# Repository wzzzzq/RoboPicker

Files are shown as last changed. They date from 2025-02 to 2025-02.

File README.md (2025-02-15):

# RoboPicker

## 项目简介

RoboPicker是一个由王子谦于2022年在华师大二附中科创班就读期间开发的机器人项目，该项目获得了上海市第37届科创大赛一等奖。RoboPicker由三个主要部分组成：底盘、机械臂和openmv相机。

## 主要研究内容 & 成果

- 麦克纳姆轮底盘的全向解耦与PID控制
- 天地飞sbus接收机的信号解码并应用于手动控制机器人
- 简单的小车自动运行程序
- 通过python为openmv编写颜色识别程序追踪果蔬
- 初步研究了使用神经网络追踪番茄
- 六轴机械臂的姿态解算与控制
- 使用PID算法控制机械臂追踪番茄
- 机械臂arduino主控，底盘arduino主控与openmv模块的uart通讯

## 仓库内容

- **代码**：在`./code`中，包含了RoboPicker的所有代码，代码分为底盘、机械臂和相机三个部分。
- **CAD文件**：在`./CADs`中，包含了RoboPicker的所有CAD设计文件。
- **arduino拓展板设计图**：`./PCB/mega_shield.pcbdoc`文件是RoboPicker的电路图。

## 结构图

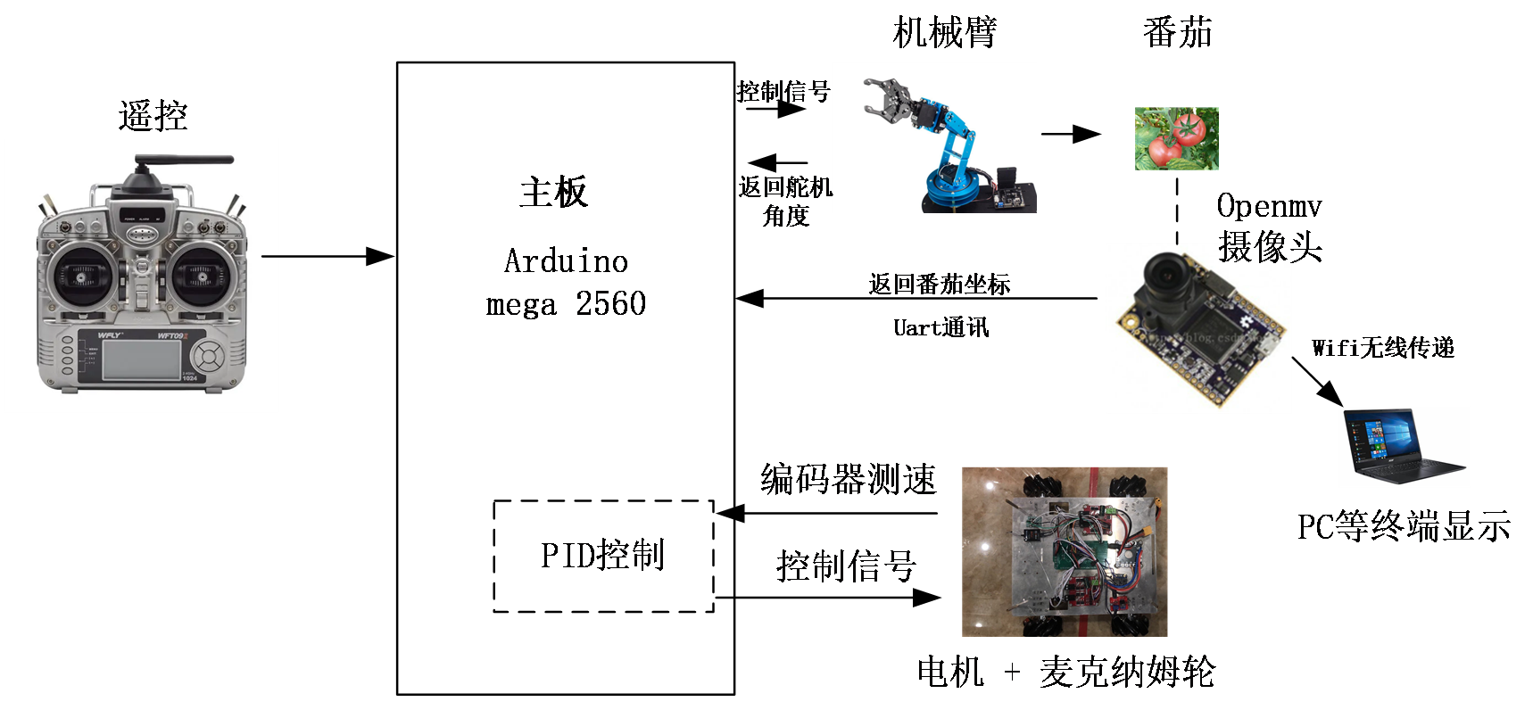
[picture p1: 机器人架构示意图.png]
机器人结构示意图


## 机器人成品展示
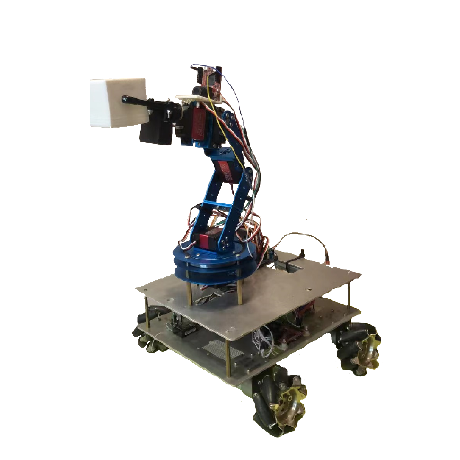
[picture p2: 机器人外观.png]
机器人外观展示


## 致谢

感谢所有为本项目提供支持和帮助的人们，特别感谢第37届科创大赛评审团对本项目的认可。

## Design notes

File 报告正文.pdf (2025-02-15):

## 第 37 届上海市青少年科技创新大赛

# 基于 Openmv 视觉识别和麦克纳姆轮

# 底盘的自动采摘番茄机器人

# 高中组 个人项目

二零二二年一月

## 基于 Openmv 视觉识别和麦克纳姆轮底盘的自动

## 采摘番茄机器人

摘 要

随着我国全面推动机器人产业发展，农业智能化进程不断提速，

从国内外农业机器人的发展来看，研制智能农业机器人，利用智能农

业机器人转变农业的生产方式，从而实现农业的可持续绿色发展是必

然的趋势。当前国内外农业机器人仍然存在智能化程度不高、采摘效

果不理想等问题。本课题秉承“智慧农业、科技创新、智能方案、机器

物联”的发展理念，分析了采摘机器人特点及国内外采摘机器人的进

展与现状，并基于此，研究基于麦克纳姆轮全向轮底盘和使用 Openmv

智能摄像头和机器视觉、人工智能技术以及六轴机械臂的智能番茄采

摘机器人。本课题实现了麦克纳姆轮底盘控制、数字 PID 闭环速度控

制、视觉识别和姿态解算算法等，并初步实现了番茄采摘机器人的智

能控制、移动行走路径规划和其他基本功能，并初步验证了自动驾驶

算法。它具有控制灵敏，动作灵活，便于操作的优点。

关键词： 机器人 麦克纳姆轮 Openmv 智能摄像头 番茄采摘 智

能控制

目录

1.1 智能农业采摘机器人研究现状·······················································3 1.2 智能农业采摘机器人发展趋势·······················································4 1.3 本文主要研究内容 ······································································4

2.1 底盘设计 ··················································································6 2.1.1 底盘设计 ··········································································6 2.1.2 电机转速读取与 PID 控制···················································10 2.1.3 遥控信号读取 ··································································11 2.1.4 电机控制 ········································································11 2.2 自动驾驶算法 ··········································································12 2.3 机械臂 ···················································································12 2.3.1 硬件设计 ········································································12 2.3.2 姿态解算 ········································································14 2.3.3 舵机控制 ········································································16 2.4 视觉识别 ················································································17 2.5 WIFI 无线通讯··········································································19

3.1 底盘运动能力测试 ····································································20 3.2 遥控信号接受测试 ····································································21 3.2.1 取反电路测试 ··································································21 3.2.2 串口通信代码测试 ····························································22 3.3 六轴机械臂测试 ·······································································23 3.3.1 姿态解算算法测试 ····························································23 3.3.2 机械臂摘取测试 ·······························································23 3.4 Openmv 摄像头测试···································································24 3.5 WIFI 模块测试··········································································25 3.6 TOF 光学测距传感器测试 ···························································26

4.1 结论 ······················································································27 4.2 展望 ······················································································27

## 第一章 前言

### 1.1 智能农业采摘机器人研究现状

“智慧农业”一词在近些年被频繁提起，各种自动化设备和监测系统也日渐

代替传统农业生产中落后、繁杂的工作。例如极飞科技等专注研发农业科技的

公司所推出的无人机产品，可以帮助农户完成打药、施肥、播种等工作，同时

还能实现多种智能监测设备，帮助农户观察作业的生长状况。

智能机器人在现代农业生产中的广泛应用，可以帮助农户解决许多繁重且

乏味的工作。以水果采摘机器人为例，每次一到果园收获时期，果场主就需要

聘请大量的人力去完成采摘的工作。而水果采摘机器人就能够帮助农场主节省

大量的时间和人力成本。

挪威环境与生命科学大学最近展出了一款名为 Noronn 的采摘机器人，这是

一款能够分辨种植在塑料隧道上的草莓成熟程度，并根据大小分类的自动采摘

机器人。这一款草莓机器人已经被欧洲的大型草莓种植园广泛采用。然而，这

一款机器人虽然可以实现 24 小时工作，但他并不适用于国内常见的田间栽培的

草莓。

美国 Abundant Robotics 公司，是近年来比较受关注的农业机器人初创科技

公司。凭借其研发的苹果采摘机器人，该公司在 2017 年就得到了 A 轮融资。

2019 年上半年，这个苹果机器人正式在新西兰投入商用。据悉，这款历时四年

研发的苹果采摘机器人备受关注。该款机器人借助先进的计算机视觉技术，采

取真空抽吸系统采摘苹果，可以准确绕开未成熟的苹果，而农场的工作人员只

需在远处进行操控即可。

我国华南农业大学研发团队早在数年前就研发出荔枝采摘机器人。机器人

效率为每小时采摘 40 斤荔枝，是人工采摘的两倍之多。这款机器人采用的是双

目立体视觉系统，可以对荔枝进行定位，获得视野内多个目标，然后自主规划

采摘作业路径进行，最后伸出机械臂末端的拟人夹指来剪断果枝，摘取果实。

除此之外还有其他各种 AI 水果采摘机器人的研发和推广都在进行当中，相

信未来的农业生产过程中，它们会为我们大幅降低成本并提高农业生产效率。

### 1.2 智能农业采摘机器人发展趋势

随着城市化的发展和农业劳动力的不断减少，新型农业生产模式的应用和新

技术的开发迫在眉睫，农业机器人将成为未来农业生产活动的核心。采摘机器人

作为农业机器人的一个重要分支，具有极大的发展潜力。

随着农业生产模式和新技术的发展和应用，农业机器人将成为农业生产的主

力军，采摘机器人作为农业机器人的重要类型具有很大的发展潜力。语音识别、

图像识别、大数据分析、运动学、传感器技术、控制技术和计算信息处理等更多

最新技术在农业机器人中的应用，使得农业数字化和智能化水平不断提高。

我国人口众多，幅员辽阔，农业是我国的支柱产业，随着智慧农业水平的提

高，采摘机器人大有用武之地。

目前，蔬果采摘机器人研究中仍然存在一些问题，例如机器人的视觉识别能

力不够，在复杂背景和夜间环境下的工作能力还不够理想等。今后应当将人机协

作，开放结构和多传感器融合的方法不断应用在农业机器人的研究中，尤其是将

人工智能、深度学习等新型技术应用于蔬果采摘机器人的技术开发之中。

### 1.3 本文主要研究内容

本课题首先对几种典型采摘机器人进行研究，分析了国内外采摘机器人的进

展与现状以及发展趋势。在此基础上，本课题基于 Openmv 视觉识别和麦克纳姆

轮底盘的自动采摘番茄机器人，机器人集可移动载体、机械手臂、夹持器、移动

机构及智能控制模块于一身，采用视觉技术、避障技术等实现了水果采摘机器人

的移动行走路径规划、果实成熟度自动判断及定位识别功能。

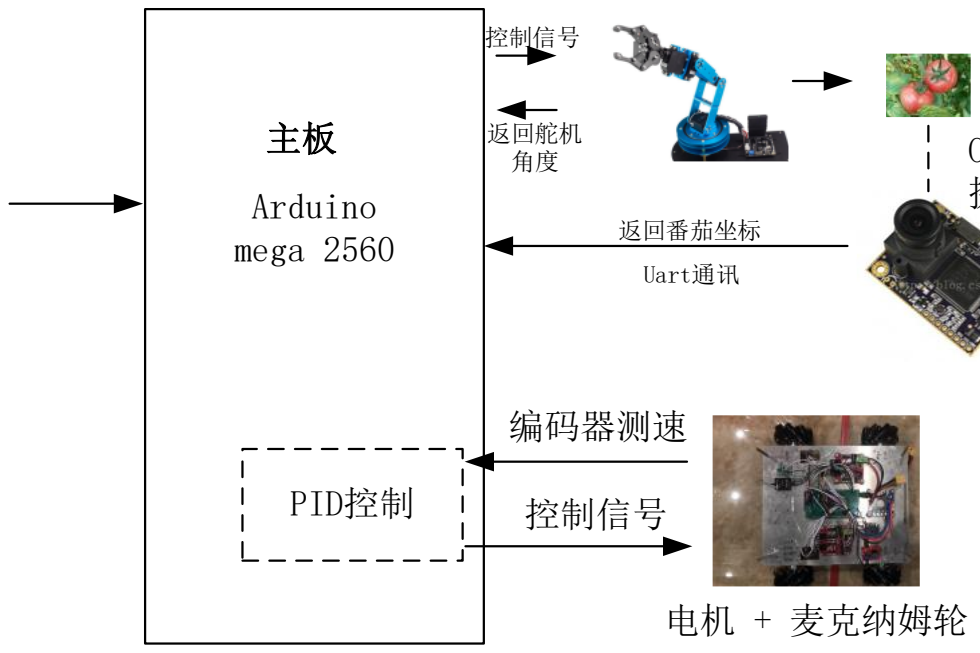
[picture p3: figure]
Arduino mega 2560; 电机 + 麦克纳姆轮; 编码器测速; PID控制; 控制信号; 返回舵机 角度; 返回番茄坐标; Uart通讯

图 1 系统结构框图

系统架构如图 1 所示，本文的组织结构如下：

第一章智能农业机器人的研究现状和发展趋势，阐述了本文的主要研究内容。

第二章阐述了本文的研究内容，包括采摘机器人的底盘设计及控制算法、机

械臂的设计和姿态解算、舵机控制，以及对于采摘机器人至关重要的视觉识别算

法及其改进。

第三章阐述了本课题农业机器人的测试过程与测试结果。

第四章总结课题，并做出了技术展望。

第五章为本课题的参考文献。

第六章则为本课题开展过程中的心得感受。

PC等终端显示

Openmv
摄像头
机械臂 | 番茄

Wifi无线传递

遥控

## 第二章 研究过程

### 2.1 底盘设计

采摘机器人集多种技术与功能于一体，其底盘作为重要部件之一，它承载

了机器人的定位导航及避障等多种功能。根据结构的不同，机器人底盘可分为

轮式、多足式及履带式等。本课题采用轮式机器人底盘，它的底盘平稳性更

好、运动噪音更低，且便于装拆及维护。本节将介绍底盘设计的具体过程，包

括底盘结构设计、电机转速读取与 PID 控制、遥控模块及电机控制。

### 2.1.1 底盘设计

轮式结构采摘机器人以驱动麦克纳姆轮来带动机器人进行移动，工作底盘设

计要实现控制麦克纳姆轮，完成各种前进、后退、左右平移、原地旋转、实物抓

取等动作。麦克纳姆轮的运动原理如图 2 所示。

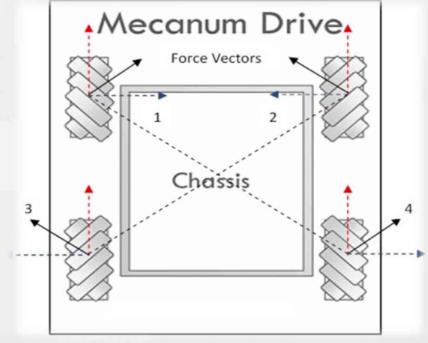
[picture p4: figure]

图 2 麦轮运动原理图

麦克纳姆轮的主要结构包括主体轮辋和回转辊子其基本结构如图 3 所示，回

转辊子均匀排布，且一般与轮辋轴线呈现 45°的夹角，这种轮子可以让机器人实

现全方向运动，但缺点是会导致运动的效率下降。

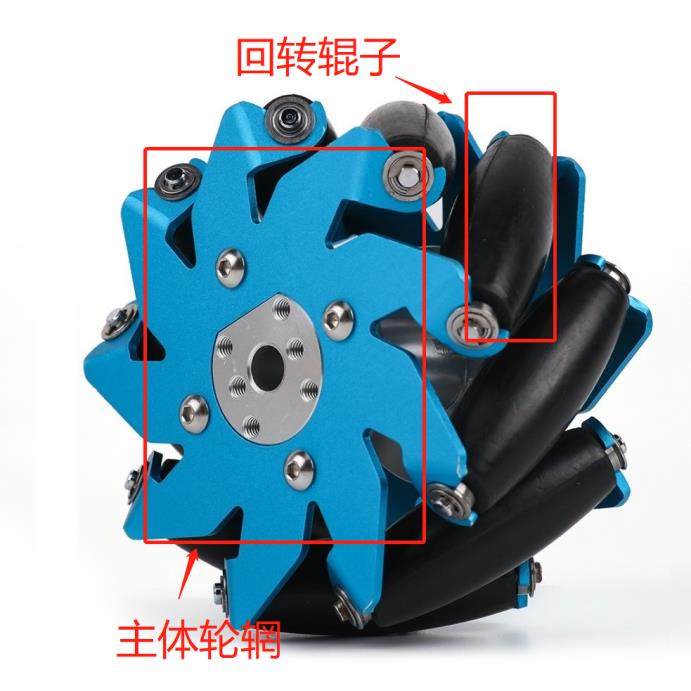
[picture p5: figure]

图 3 麦轮结构图

因为本课题中的工作环境要求机器人在移动时精确且平稳，同时在执行工作

时其底盘也要有相当的载荷能力和稳定性。所以在轮组布局上，本课题采用稳定

性较高的四轮布局，并以铝合金材料为底盘材料。驱动方式则选择四轮驱动的方

式，以提高稳定性和电机利用率。

基于此进行底盘的结构设计，并要求移动底盘能符合载荷和工作速度。底盘

在 Solidworks 软件中的 3D 模型如图 4 所示。

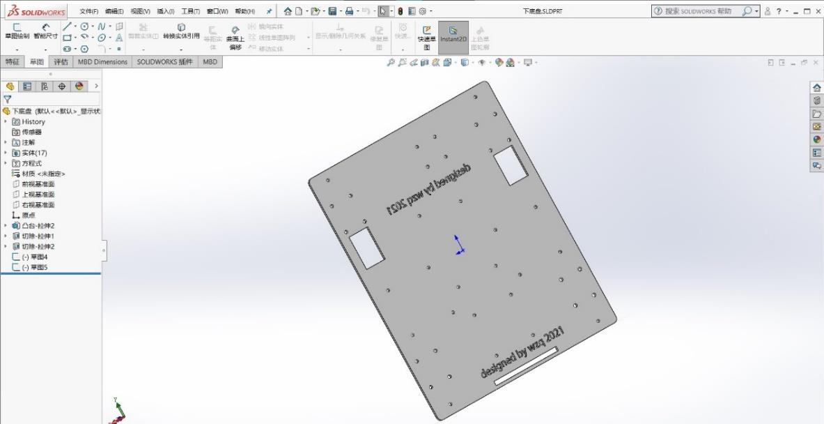
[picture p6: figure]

图 4 底盘 3D 模型

加工后的底盘如图 5 所示。

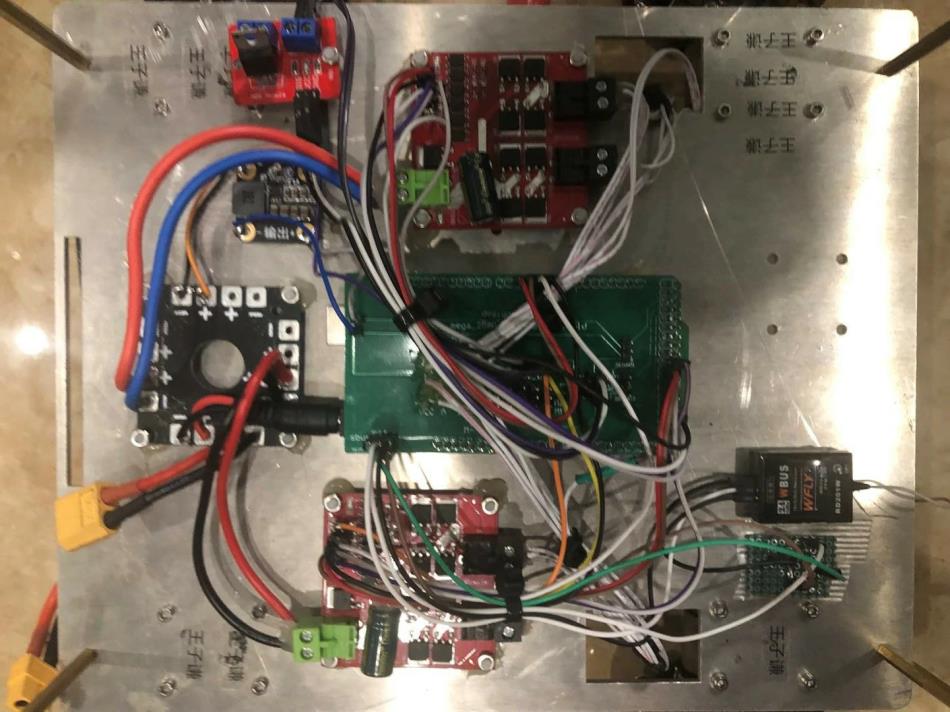
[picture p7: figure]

图 5 加工后的底盘

底盘控制板采用 Arduino mega 2560 芯片开发板，在上面设计了拓展板，拓

展板集成了电机控制与通讯，供电，机械臂控制，遥控器通讯，降压电路等等。

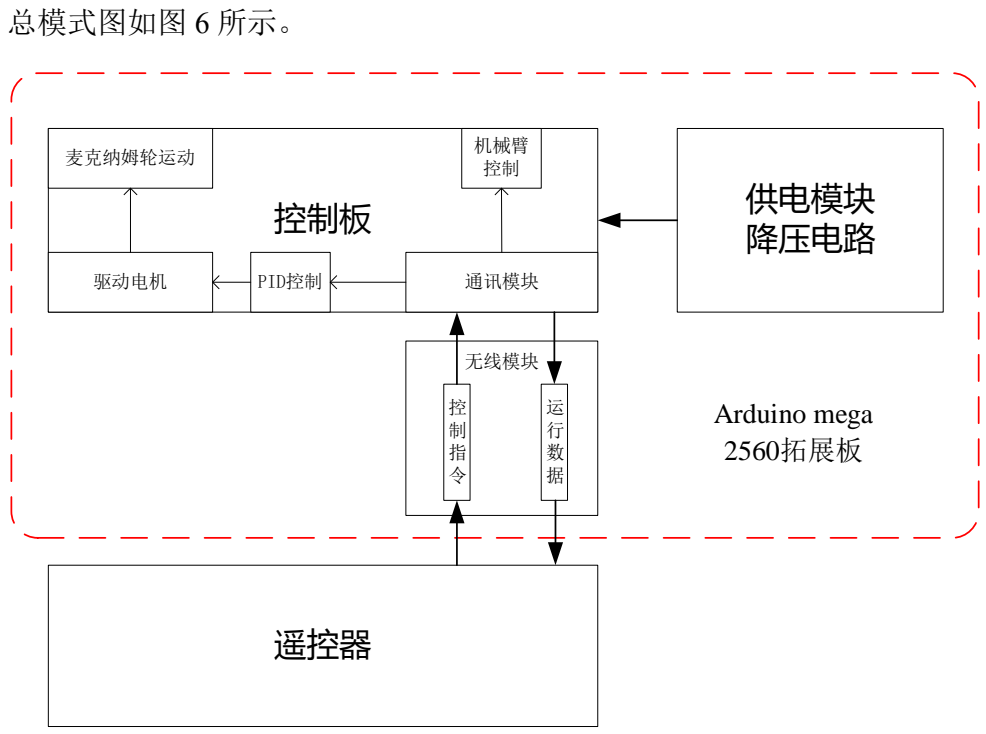
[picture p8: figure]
总模式图如图 6 所示。; 遥控器; 无线模块; 控制板; 驱动电机; PID控制; 通讯模块; 麦克纳姆轮运动; 机械臂; 供电模块 降压电路; Arduino mega 2560拓展板

图 6 电路模式图

拓展电路板使用 Altium designer 设计，设计图纸如图 7 所示。

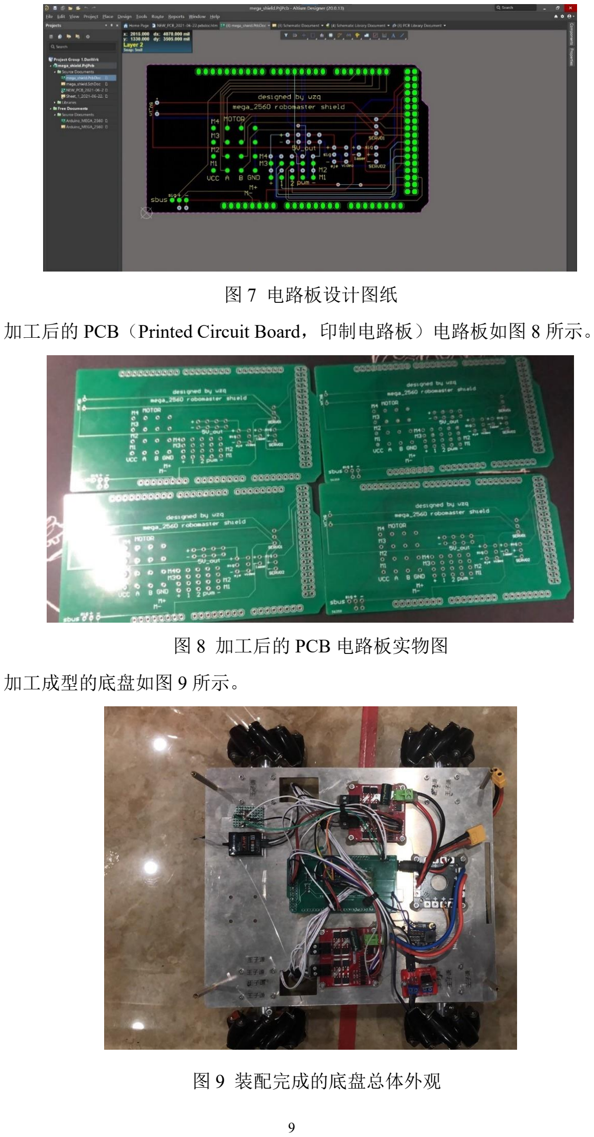
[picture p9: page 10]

图 7 电路板设计图纸

加工后的 PCB（Printed Circuit Board，印制电路板）电路板如图 8 所示。

图 8 加工后的 PCB 电路板实物图

加工成型的底盘如图 9 所示。

图 9 装配完成的底盘总体外观

### 2.1.2 电机转速读取与 PID 控制

本课题采用增量式霍尔编码器来测量电机转速，霍尔编码器是通过磁电转换

将输出轴上的机械几何位移量转换成脉冲或数字量的传感器，其原理如图 10 所

示。增量式编码器是将设备运动时的位移信息变成连续的脉冲信号，通过在一定

时间内对脉冲信号进行计数来测量电机位移量。

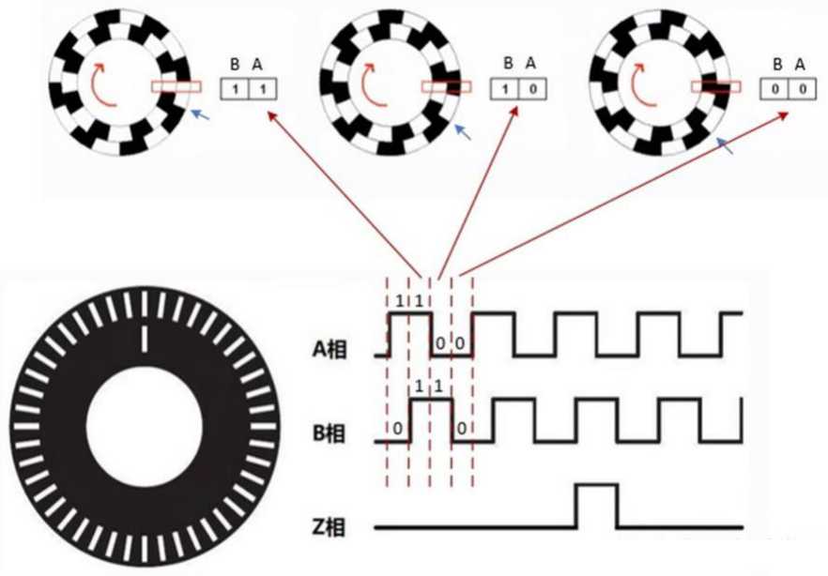
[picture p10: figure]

图 10 霍尔编码器工作原理

根据上图所示的原理，当 ABZ 相脉冲发生变化时，将会触发 MCU

（Microcontroller Unit，微控制单元）中断响应，中断服务函数将为脉冲进行计数，

计数周期为 30ms，每个计数周期结束，中断服务函数将脉冲数量 in1 赋值给速

度变量 M1S，同时 in1 清零，并且开始下一周期的计数。得到的电机转速，将作

为 PID（Proportion Integral Differential，比例积分差分）控制的输入反馈，实现

电机转速的闭环控制。

电机转速的指令信号，也就是电机转速闭环控制的参考值来自于机器人的遥

控器，指令信号必须映射到机器人的三个运动方向（偏航、平移运动、前后运动）

才能实现对机器人的平滑控制，同时也让机器人能进行更加复杂的组合运动。但

这种控制方法的缺陷在于，如何把霍尔编码器采集得到的数字信号，准确快速地

反映到 PID 控制算法的实际程序中，其中一个比较重要的问题就是电机的转向。

例如，当电机一开始是正转，而下一时刻的控制信号是反转时，如果程序中，转

速只是一个无符号的标量值，则会导致 PID 的输出出现错误，如目前控制信号时

正转 20，下一个控制信号是反转 30，PID 的误差输出理应是|30-(-20)|=50，但如

果没有事先判断这两个信号在方向上不同，则会导致 PID 的误差输出为|30-

20|=10，这显然是错误的。

利用霍尔编码器输出的 AB 两相脉冲出现的顺序可以很好地解决上面的问题，

当 A 相计数脉冲超前于 B 相计数脉冲时，我们视为电机正转，B 相脉冲超前于

A 相脉冲时，我们视为电机反转，则可以在程序中增加一个转向判断标志位，通

过监测编码器中传来的 AB 相脉冲的先后顺序，来对转向判断标志位进行置 0 或

者置 1，由此完成对电机转向的判断。

### 2.1.3 遥控信号读取

本课题采用了天地飞 9 的遥控和 Sbus 接收机，Sbus 是一种协议,它与 Uart

类似,可以与单片机通过串口通信(Serial)。

Sbus 接收机相对于传统接收机有很多好处。传统的 PWM（Pulse width

modulation，脉冲宽度调制）接收机读取速度慢,每一个读取周期大约需要 2ms,阻

碍程序进行。并且 PWM 接收机精度低，还会被外部中断干扰。而 Sbus 接收机

耗时少,精度高,不会受干扰。经过测试，Sbus 接收机的读取周期几乎可以忽略不

计,并且信号很稳定,不易受外部干扰,有利于机器人的稳定和精准控制。

然而 Sbus 接收机的缺陷是其读取算法比较复杂,而且 Sbus 的原始信号需要

经过取反电路才能被主板正确读取。取反电路如下图 11。

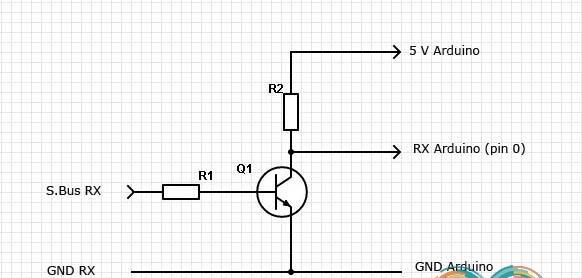
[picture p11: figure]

图 11 取反电路电路图

### 2.1.4 电机控制

电机的控制策略是机器人运动过程中的一个非常重要的环节，电机能否根据

遥控器的指令进行平滑的运动，是衡量控制策略好坏的一个重要指标。传统的电

机控制策略是直接读取遥控器的指令输出值，直接根据遥控器信号开度来决定电

机的转矩大小，这种控制策略简单快速，但如果操作人员操作不熟练，或者控制

信号产生抖动，会导致电机转矩信号的剧烈抖动，反映到机器人的运动上的就是

卡顿或突然加速等情况，这将导致控制的不顺滑。

本设计提出了一种新颖的控制策略，首先对遥控器的指令信号进行读取，根

据指令信号，计算得出机器人整体需要的运动方向、运动加速度等信息，再对这

些信息进行进一步的分解，得出机器人纵向运动、横向运动、旋转运动三个维度

对应的参考值，为了让机器人的运动更加顺滑，四个轮子对应的电机将根据这三

个参考值，在矢量控制法的基础上，给出四个相互独立的参考值，从而实现不同

车轮之间的解耦控制，使得机器人的运动更加顺滑。控制的基本框图如图 12 所

示。

读取控制器指令 | 指令分解

横向运动
纵向运动
旋转运动
矢量控制算法 | 驱动信号发生器

左前轮
左后轮
右前轮
右后轮

电机驱动器

左前轮
左后轮
右前轮
右后轮

机器人运动

图 12 电机控制算法流程图

### 2.2 自动驾驶算法

在底盘控制算法的基础上，机器人可以进一步实现自动驾驶算法。将农田

的地图和规划好的路线导入机器人的 MCU 中，机器人就可以实现自动收割。

机器人在识别到番茄以后执行摘取程序并收获番茄，之后继续按照规划路线向

前行驶，直到识别到下一个番茄。

### 2.3 机械臂

### 2.3.1 硬件设计

本课题使用如图 13 所示的六轴机械臂采摘番茄。

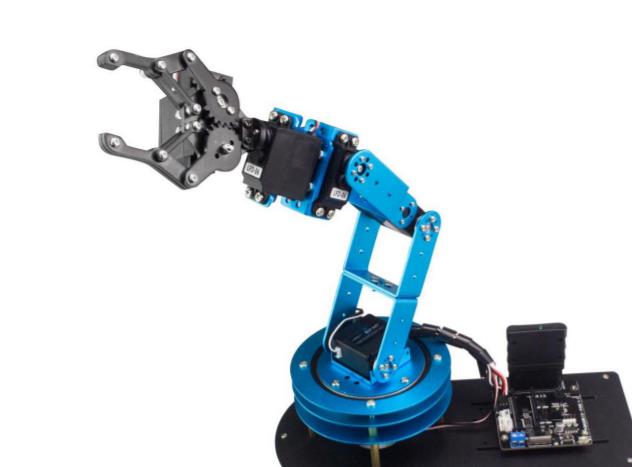
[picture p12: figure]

图 13 六轴机械臂

整套机械臂一共使用了 6 个高精度数字舵机 我们从上往下看。爪子部分使

用的是具有防堵转功能的 LDX-335MG 数字舵机，当发生堵转时，舵机会自动

计时，当发现堵转超过 4 分钟时，舵机会自动停止工作。接下来两个舵机是

LFD-06 防堵转低功耗的数字舵机，当发生堵转时，舵机内部会自动进行保护。

在云台上面的两个舵机是高精度的双轴数字舵机，它们采用插拔的连接方式，布

线、更换都十分方便。最后底座上的舵机采用大扭力的 1501 舵机，它有 15KG

的扭力，能旋转 180°。六轴机械臂控制算法复杂，需要与主板进行实时通信，所

以本课题设计了一块通信电路板，设计图如下图 14 所示。

图 14 机械臂主控板通讯电路板原理图

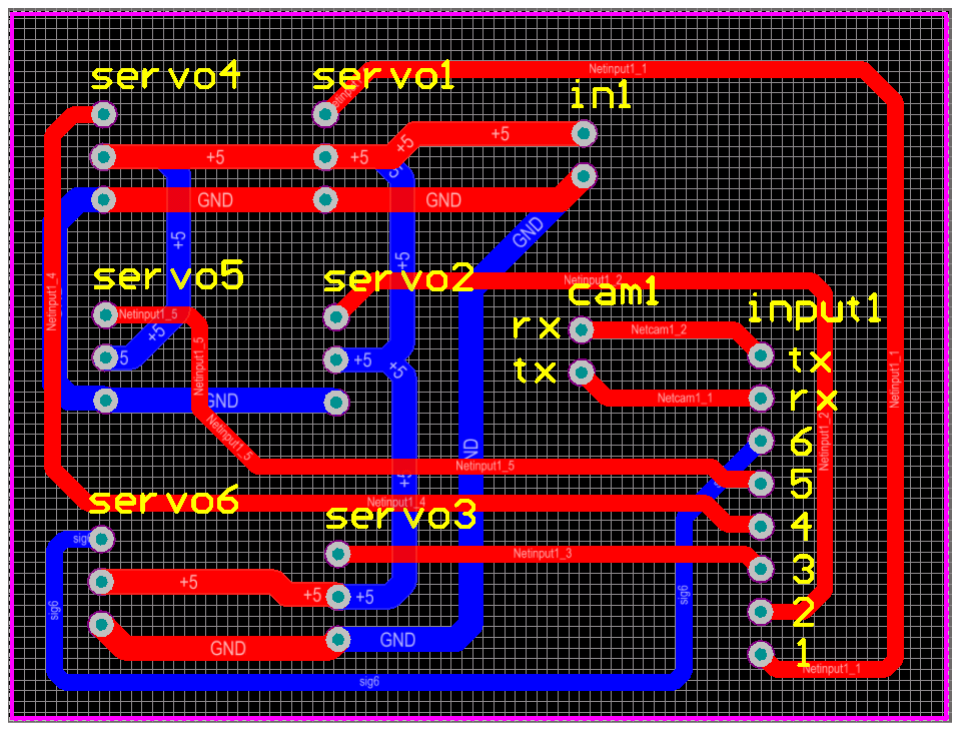
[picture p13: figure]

图 15 机械臂主控板通讯电路板电路图

### 2.3.2 姿态解算

姿态解算是采摘机器人的一个基础、重要部分，其作用是估计出来的姿态

会发布给姿态控制器，控制机器人运动。姿态解算的关键是理解关于坐标系的

概念、姿态角的几种描述方法，以及物体从一个姿态经过运动变化到另一个姿

态，并把这个中间过程简化为一种变换关系。

首先对机械臂进行数学建模，如图 16 所示，取机械臂底部舵机作为原点,

通过每个舵机当前的角度解算出机械剪刀当前的坐标,通过摄像头返回的数据算

出目标物体(番茄)的坐标。然后通过方程解出机械臂要达到目标物体,每个舵机

需要转动的角度。

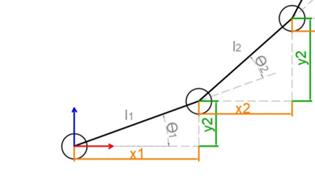
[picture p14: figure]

图 16 机械臂数学模型

根据上述模型采用几何画板软件进行仿真的过程如图 17 所示。

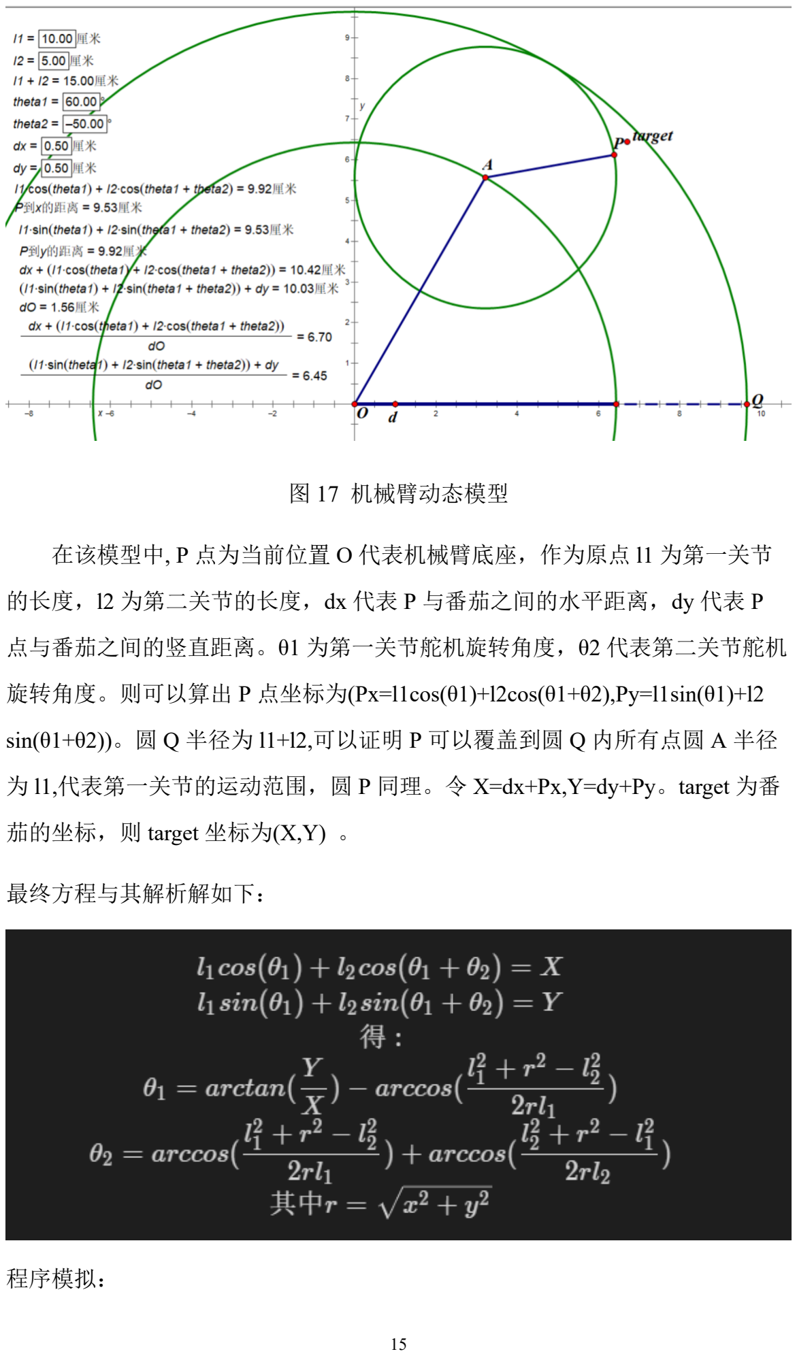
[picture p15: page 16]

图 17 机械臂动态模型

在该模型中, P 点为当前位置 O 代表机械臂底座，作为原点 l1 为第一关节

的长度，l2 为第二关节的长度，dx 代表 P 与番茄之间的水平距离，dy 代表 P

点与番茄之间的竖直距离。θ1 为第一关节舵机旋转角度，θ2 代表第二关节舵机

旋转角度。则可以算出 P 点坐标为(Px=l1cos(θ1)+l2cos(θ1+θ2),Py=l1sin(θ1)+l2

sin(θ1+θ2))。圆 Q 半径为 l1+l2,可以证明 P 可以覆盖到圆 Q 内所有点圆 A 半径

为 l1,代表第一关节的运动范围，圆 P 同理。令 X=dx+Px,Y=dy+Py。target 为番

茄的坐标，则 target 坐标为(X,Y) 。

最终方程与其解析解如下：

程序模拟：

#include<bits/stdc++.h>

using namespace std;

const double pi=3.1415926;

double angle(double x)

{

return x*pi/180;

}

int main()

{

double xp,yp,t1,t2,T1,T2,X,Y,dx,dy,l1=10,l2=5,r;

r=sqrt(X*X+Y*Y);

xp=l1*cos(t1)+l2*cos(t1+t2);

yp=l1*sin(t1)+l2*sin(t1+t2);

X=xp+dx;

Y=yp+dy;

T1=atan(Y/X)+acos(l1*l1+r*r-l2*l2);

T2=acos((l1*l1+r*r-l2*l2)/2*r*l1)+acos((l2*l2+r*r-

l1*l1)/2*r*l2);

cout<<T1<<" "<<T2;

}

### 2.3.3 舵机控制

舵机内部包括了一个小型直流马达；一组变速齿轮组；一个线性反馈电位

器；以及一块控制电路板。其中，高速转动的直流马达提供了舵机的原始动

力，带动减速齿轮组，使之产生高扭力的输出，齿轮组的变速比愈大，舵机的

输出扭力也愈大，也就是说越能带动更大重量的负载（受齿轮强度限制），但输

出的转速（响应速度）也愈低。

17 0.5ms

输入正脉冲宽度（周期为20ms） | 舵机输出臂位置 ≈ | ° - 90 ≈ | ° - 45 ≈° 0 ≈ | ° 45 ≈ | ° 90

图 18 舵机角度与脉冲关系

如图 18 所示，舵机的瞬时运动速度是由其内部的直流马达和变速齿轮组的

配合决定的，在恒定的电压驱动下，其数值唯一。对于数字 PWM 舵机，其速

度由其内部程序确定，一般但其平均运动速度可通过分段停顿的控制方式来改

变，例如，我们可把动作幅度为 90°的转动细分为 128 个停顿点，通过控制每

个停顿点的时间长短来实现 0°—90°变化的平均速度。于多数舵机来说，速度

的单位由“度数/秒”来决定。

### 2.4 视觉识别

本课题中采用如图 19 所示的 Openmv 摄像头识别番茄，OpenMV 是一个开

源，低成本，功能强大的机器视觉模块。以 STM32F427CPU 为核心，集成了

OV7725 摄像头芯片，在小巧的硬件模块上，用 C 语言高效地实现了核心机器视

觉算法，提供 Python 编程接口。本课题正是用 Python 语言使用 OpenMV 提供的

机器视觉功能。

图 19 OpenMV 机器视觉模块

如图 20 所示，本课题中的机器视觉算法包括寻找色块、标志跟踪等，给采

摘机器人提供环境感知和番茄识别功能等。并以大量数据和图片为基础，通过算

法实现对于机器的训练。

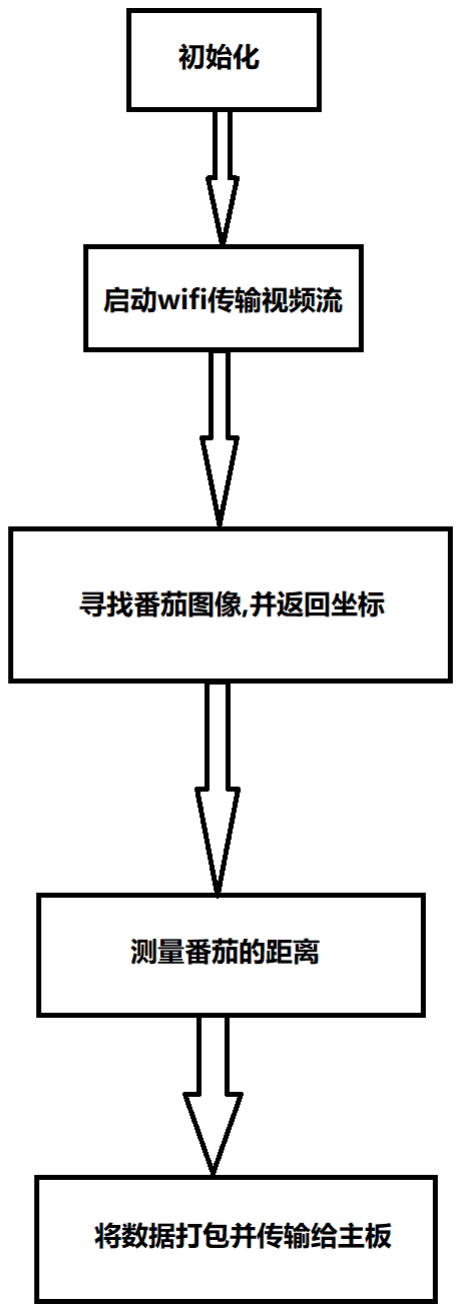
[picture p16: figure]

图 20 摄像头视觉识别算法流程

### 2.5 WIFI 无线通讯

本课题中除了使用遥控传递信号外，还使用了如图 21 所示的 WIFI 通讯模

块通讯，两种通讯方式各有优缺点，相结合可以达到更好的通讯效果。WIFI 通

讯有开发方便，传输数据量大的特点，可以传输实时视频图像。但是 WIFI 通讯

距离较短，本课题使用 WIFI 模块传输视频流，使用电脑实时观看采摘过程。

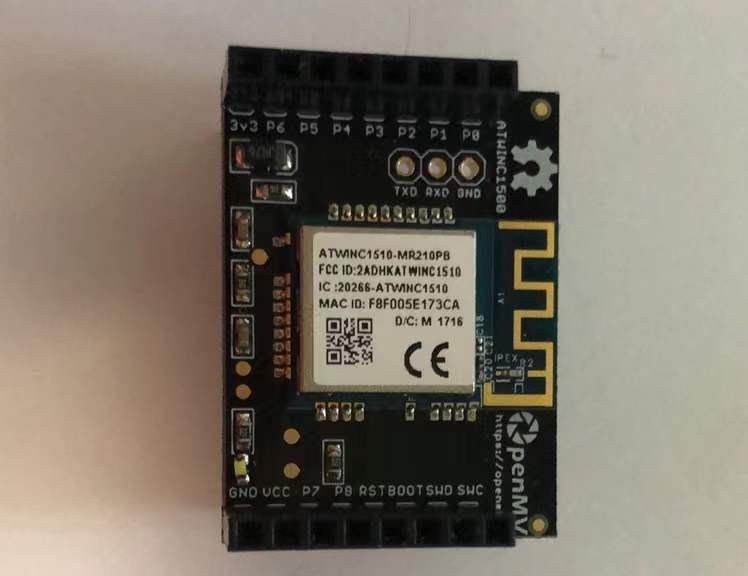
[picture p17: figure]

图 21 WIFI 无线通讯模块

## 第三章 测试过程与测试结果

本课题搭建的自动采摘机器人外观如图 22 所示.

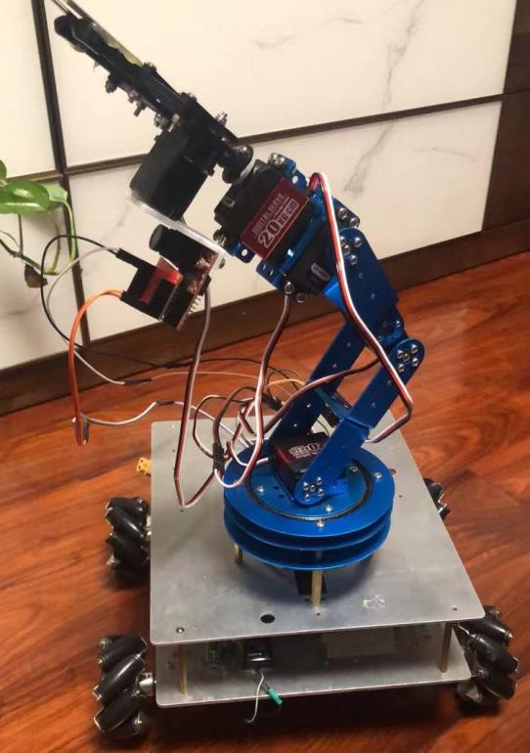
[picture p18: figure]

图 22 所搭建的自动采摘机器人外观

本章将分不同部分介绍本机器人测试过程与结果。

### 3.1 底盘运动能力测试

调试视频 (https://www.bilibili.com/video/BV13B4y1N7Dm?spm_id_from=333.999.0.0)

图 23 调节电机 PID 参数

首先要对 PID 参数进行调节，使电机的转速曲线尽量稳定。经过调节找到最

优的参数后，底盘的运动的轨迹非常趋近于直线。

移动视频 (https://www.bilibili.com/video/BV1Kb4y1k7fu?spm_id_from=333.999.0.0)

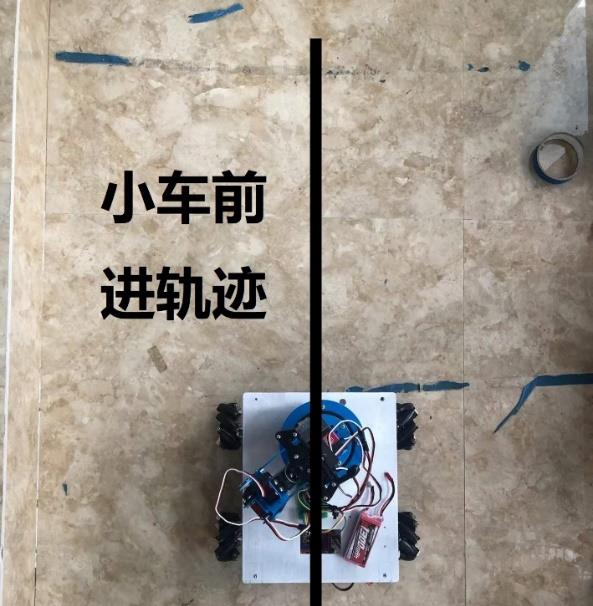
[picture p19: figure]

图 24 底盘走直线测试

### 3.2 遥控信号接受测试

### 3.2.1 取反电路测试

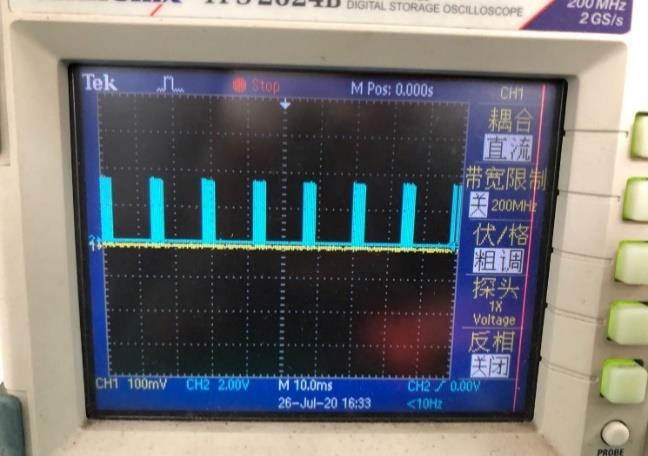
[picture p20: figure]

图 25 取反前的 Sbus 信号

图 26 取反后的 Sbus 信号

经过测试,取反电路达到了预期功能。

### 3.2.2 串口通信代码测试

一开始串口通信无法工作，后来发现原因为 Arduino 主板的 Serial0 用于和

电脑通讯，故更换为 Serial1 和 Sbus 接收机通讯，通讯成功。

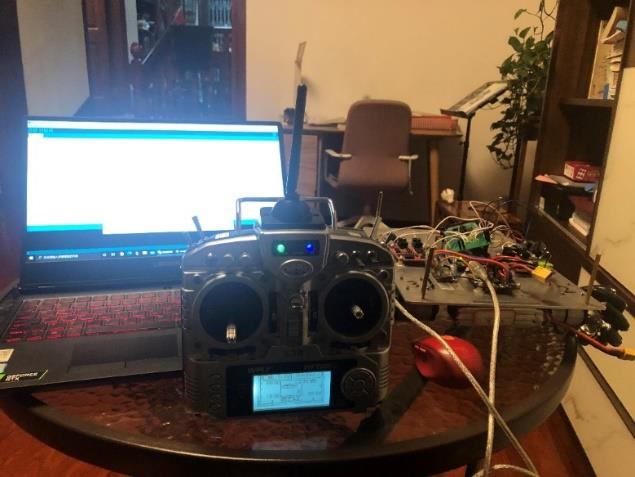
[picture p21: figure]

图 27 Sbus 信号读取成功

### 3.3 六轴机械臂测试

### 3.3.1 姿态解算算法测试

本课题使用几何画板建立了动态模型，如图 28 为目标物体的坐标。

图 28 几何画板中目标物体的坐标

下图为程序计算的舵机旋转角度。

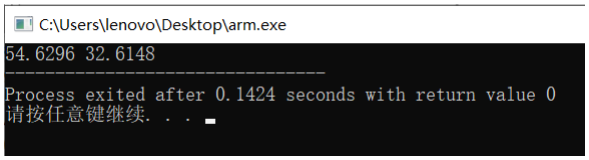
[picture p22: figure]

图 29 程序计算的舵机输出角度

将该角度代入模型，得到的机械臂坐标与目标物体一致，计算正确

图 30 数据代入几何画板后的机械臂坐标

### 3.3.2 机械臂摘取测试

图 31 给出了摘取前后机械臂的动作，可以看到，机械臂可以将果蔬切下。

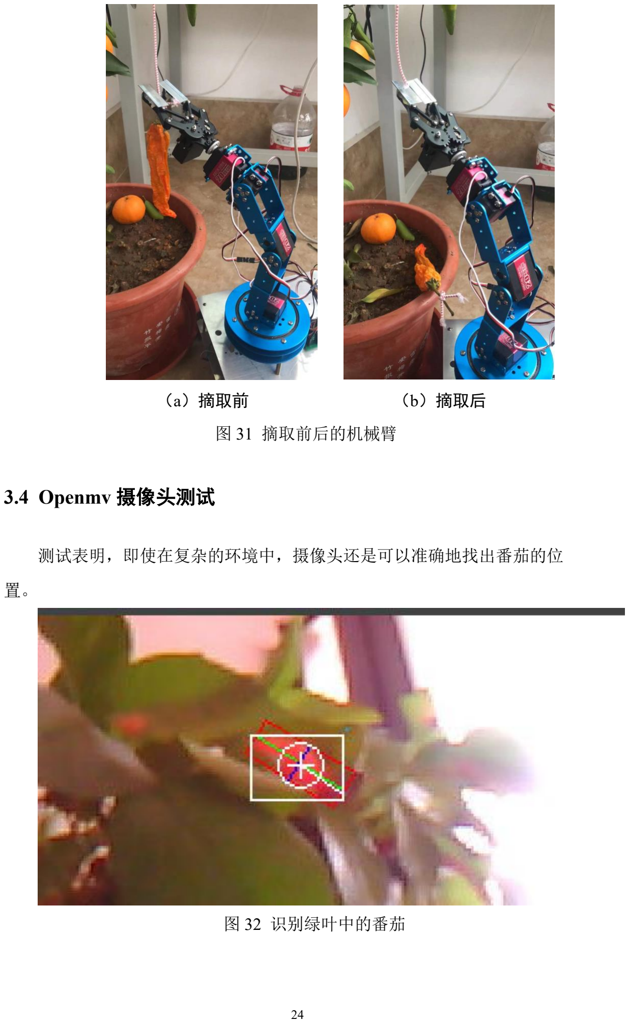
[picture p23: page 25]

（a）摘取前 | （b）摘取后

图 31 摘取前后的机械臂

### 3.4 Openmv 摄像头测试

测试表明，即使在复杂的环境中，摄像头还是可以准确地找出番茄的位

置。

图 32 识别绿叶中的番茄

图 33 识别地上的番茄

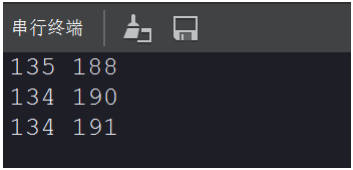
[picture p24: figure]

图 34 摄像头返回的番茄位置信息

### 3.5 WIFI 模块测试

经过测试，电脑或手机可以连接 WIFI，并通过特定地址查看视频流，延时

很低。

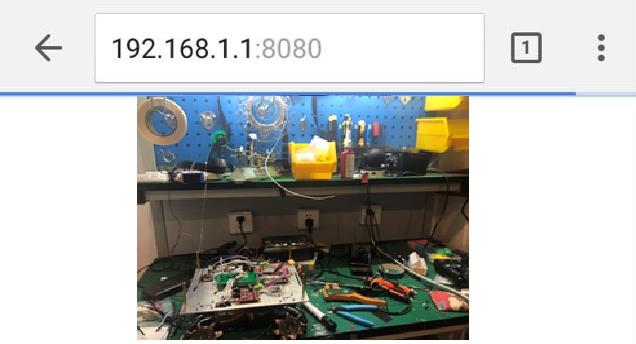
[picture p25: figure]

图 35 手机接收到的实时图像

### 3.6 TOF 光学测距传感器测试

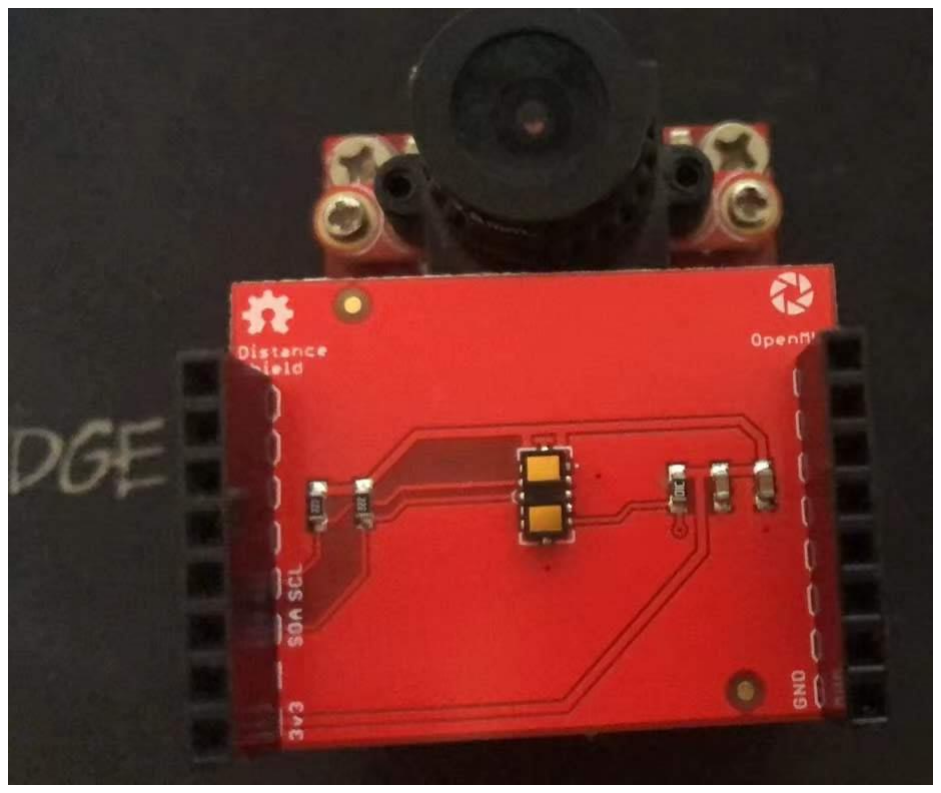
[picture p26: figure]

图 36 TOF 光学测距传感器
经过测试，TOF 传感器测距精度很高，可以达到 mm 级精度，并且延时很

低，可以准确测量番茄的距离。

## 第四章 结论与展望

### 4.1 结论

本课题利用麦克纳姆轮底盘控制、数字 PID 闭环速度控制、视觉识别和姿态

解算算法等初步实现了蔬果采摘机器人的智能控制和基本功能。它具有控制灵敏，

动作灵活，便于操作的优点。下一步可以在图像识别等方面进行改进。由于时间

限制，自动驾驶算法还很不完善，下一步将后续引入更先进的算法。

### 4.2 展望

今后可以在本课题已有成果基础上，增加机器人在复杂背景和夜间环境下的

视觉识别能力。并融合多传感器，植入人工智能、深度学习等新型技术。

## 第五章 参考文献

[1] 马瑛，杨旭, 草莓采摘机器人成熟果实识别及避障控制系统研究—基于 ARM

与 FPGA [J]. 农机化研究, 2020, 40(1):1-18.

[2] 谭涛，蔬果采摘机器人的研究进展与展望 [J]，现代农业研究，2020（5）.
[3] 王文杰，贡亮，汪韬等，基于多源图像融合的自然环境下番茄果实识别，农

业机械学报，2021（9）.

[4] 郭婷，孙艺伟等，全球农业传感器技术研发态势分析[J]，中国农业信息，2020

（3）.

[5] 李高铭，聂卓赟等，非平衡负载下轮式移动机器人的抗扰 PID 控制[J]，《控

制理论与应用》，2021（3）.

[6] 赖永林，方建文等，基于 Arduino 单片机的增量式编码器模拟装置设计[J]，

工业控制计算机，2021（5）.

## 第六章 心得感受

本课题从最初的想法，到框图设计，图纸设计，到买物料，搭建实验系统，

建模，编程和调试，我学习到了很多知识。我觉得要解决一个较为复杂的工程

问题，需要在平时积累非常多的知识和能力。同时，在调试过程中，一些看似

简单的问题，可能会有意想不到的困难，而解决这些困难，需要细致耐心，仔

细观察和思考。

看着自己的想法从图纸和代码变成了现实，整个过程带给我成就感和快乐，

我会在科创这条道路上继续前行！

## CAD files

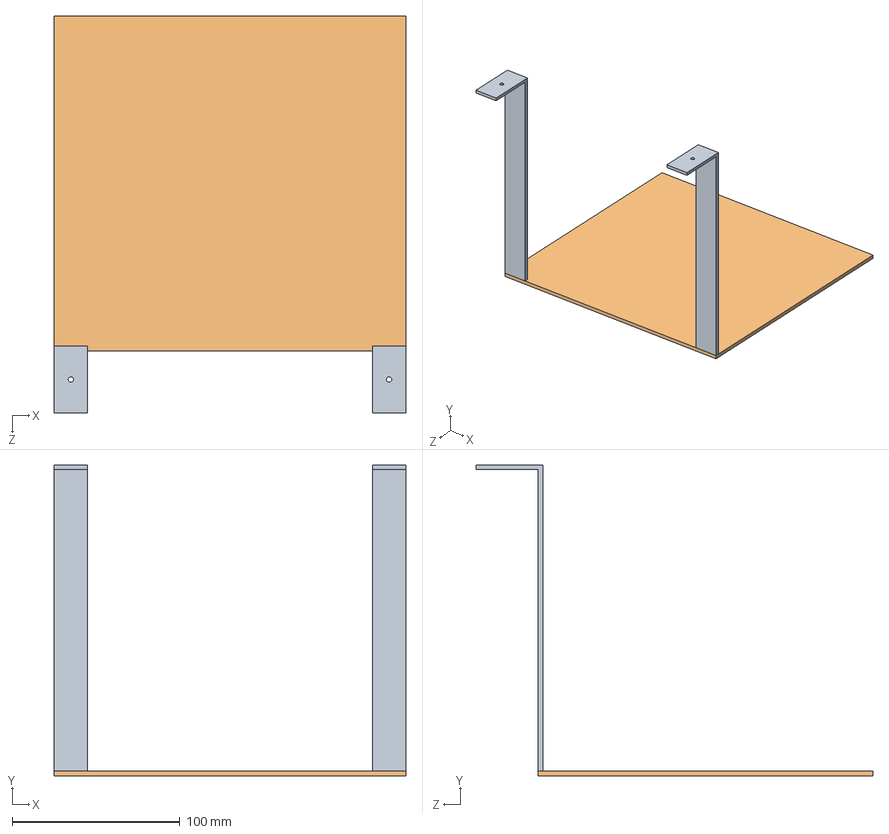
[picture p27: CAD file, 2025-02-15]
CADs/computer brace.STEP
210.0 x 185.5 x 237.0 mm

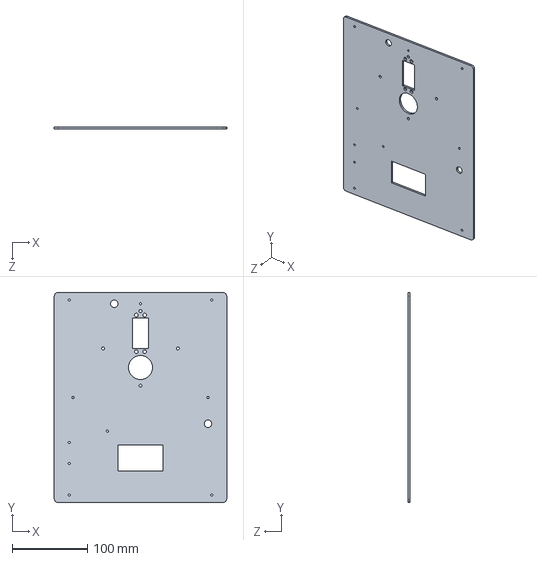
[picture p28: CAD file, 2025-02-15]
CADs/upper chassis.STEP
230.0 x 280.0 x 3.00 mm

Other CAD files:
CADs/lower bassis.STEP
CADs/computer brace.SLDPRT
CADs/lower bassis.SLDPRT
CADs/upper chassis.SLDPRT

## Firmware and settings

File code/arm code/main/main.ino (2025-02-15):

#include <Servo.h>                // 声明调用Servo.h库
#include <PID_v1.h>
#define  SERVO_NUM  6             //舵机数量
Servo myservo[SERVO_NUM];         //创建六个舵机类
const  byte servo_pin[SERVO_NUM] = {10, A2, A3, A0, A1, 7}; //宏定义舵机控制引脚

int data[10], cnt, l, num;

int ServoPwmDuty[8] = {1500, 1500, 1500, 1500, 1500, 1500, 1500, 1500}; //PWM脉冲宽度
int ServoPwmDutySet[8] = {1500, 1500, 1500, 1500, 1500, 1500, 1500, 1500}; //PWM脉冲宽度
double ServoPwmDutyInc[8];   //为了速度控制，当PWM脉宽发生变化时，每2.5ms或20ms递增的PWM脉宽

double cx = 93, cy = 61, Kpx = 0.2, Kpy = 0.4,  xnow, ynow;
double angle[10] = {1500, 1500, 1800, 800, 1500, 1500, 500};

bool ServoPwmDutyHaveChange = 0;  //脉宽有变化标志位
bool found = 0;

int ServoTime = 5000;      //舵机从当前角度运动到指定角度的时间，也就是控制速度

unsigned long t, T;

void ServoSetPluseAndTime(int id, int p, int time)
{
  if (id >= 0 && id < 6 && p >= 500 && p <= 2500)
  {
    if (time < 20)
      time = 20;
    if (time > 30000)
      time = 30000;
    ServoPwmDutySet[id] = p;
    ServoTime = time;
    ServoPwmDutyHaveChange = 1;
  }
}

void ServoPwmDutyCompare(void)//脉宽变化比较及速度控制
{
  int i;

  static int ServoPwmDutyIncTimes; //需要递增的次数
  static bool ServoRunning = 0; //舵机正在以指定速度运动到指定的脉宽对应的位置
  if (ServoPwmDutyHaveChange) //停止运动并且脉宽发生变化时才进行计算      ServoRunning == 0 &&
  {
    ServoPwmDutyHaveChange = 0;
    ServoPwmDutyIncTimes = ServoTime / 20; //当每20ms调用一次ServoPwmDutyCompare()函数时用此句
    for (i = 0; i < 6; i++)
    {
      //if(ServoPwmDuty[i] != ServoPwmDutySet[i])
      {
        if (ServoPwmDutySet[i] > ServoPwmDuty[i])
        {
          ServoPwmDutyInc[i] = ServoPwmDutySet[i] - ServoPwmDuty[i];
          ServoPwmDutyInc[i] = -ServoPwmDutyInc[i];
        }
        else
        {
          ServoPwmDutyInc[i] = ServoPwmDuty[i] - ServoPwmDutySet[i];
        }
        ServoPwmDutyInc[i] /= ServoPwmDutyIncTimes;//每次递增的脉宽
      }
    }
    ServoRunning = 1;  //舵机开始动作
  }
  if (ServoRunning)
  {
    ServoPwmDutyIncTimes--;
    for (i = 0; i < 6; i++)
    {
      if (ServoPwmDutyIncTimes == 0)
      { //最后一次递增就直接将设定值赋给当前值
        ServoPwmDuty[i] = ServoPwmDutySet[i];
        ServoRunning = 0; //到达设定位置，舵机停止运动
      }
      else
      {
        ServoPwmDuty[i] = ServoPwmDutySet[i] + (signed short int)(ServoPwmDutyInc[i] * ServoPwmDutyIncTimes);
      }
      myservo[i].writeMicroseconds(ServoPwmDuty[i]);
    }
  }
}
void GetData()
{
  found = 0;
  if (Serial.available())
  {
    found = 1;
    char input = Serial.read();
    while (input != '[' && input != -1)   input = Serial.read();
    if (input != -1)
    {
      String s = Serial.readStringUntil(']'), numstr = "";
      l = s.length(), cnt = 0;
      for (int i = 0; i < l; i++)
      {
        if (isDigit(s[i]))
          numstr += s[i];
        if (s[i] == ',' || i == l - 1)
        {
          data[++cnt] = numstr.toInt();
          numstr = "";
        }
      }
    }
  }
  xnow = data[1];
  ynow = data[2];
}
void PrintData()
{
  for (int i = 1; i <= cnt; i++)
  {
    Serial.println(data[i]);
  }
  Serial.println("==========");
}

void compute_x(int ref, int real)
{
  double error = 0;
  error = ref - real;
  angle[1] += Kpx * error;
  angle[1] = min(2500, angle[1]);
  angle[1] = max(500, angle[1]);
}

void compute_y(int ref, int real)
{
  double error = 0;
  error = ref - real;
  angle[2] += Kpy * error;
  angle[2] = min(2500, angle[2]);
  angle[2] = max(500, angle[2]);
  if (angle[2] > 1500) angle[4] = angle[2] - 1000;
  //else angle[3] = angle[2];
}

void aim()
{
  if (abs(xnow - cx) > 2) compute_x(cx, xnow);
  if (abs(ynow - cy) > 2) compute_y(cy, ynow);
  if (data[3] >= 7 && data[3] <= 9)  angle[6] = 1000;
  else  angle[6] = 500;
}
void def()
{
  angle[1] = angle[5] = angle[7] = 1500;
  angle[2] = 1800;
  angle[3] = 1500;
  angle[4] = 800;
}

void setup() {
  //put your setup code here, to run once:
  Serial.begin(9600);
  pinMode(3, INPUT);
  for (byte i = 0; i < SERVO_NUM; i++ ) {
    myservo[i].attach(servo_pin[i]);    // 将10引脚与声明的舵机对象连接起来
  }
  def();
  t = millis() + 20;
  T = millis() + 300;
}

void loop() {
  //put your main code here, to run repeatedly:
  GetData();
  if (millis() > t)
  {
    if (digitalRead(3)) angle[6] = 500;
    if (ServoPwmDuty[5] == 1000)
    {
      def();
    }
    if (ServoPwmDuty[5] == 500)
    {
      if (!found) num++;
      else num = 0;
      if (num < 10) aim();
      ///Serial.println(1);
    }
    for (int i = 0; i < 6; i++)  ServoSetPluseAndTime(i, angle[i + 1], 60);
    ServoPwmDutyCompare();
    t = millis() + 20;
  }
  //PrintData();
  //Serial.println(ServoPwmDuty[5]);
  //Serial.println(gripped);
}

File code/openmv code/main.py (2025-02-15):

# AprilTags Example
#
# This example shows the power of the OpenMV Cam to detect April Tags
# on the OpenMV Cam M7. The M4 versions cannot detect April Tags.

import sensor, image, time, math, pyb
from pyb import UART,LED
sensor.reset()
sensor.set_pixformat(sensor.RGB565)
sensor.set_framesize(sensor.QQVGA) # we run out of memory if the resolution is much bigger...
sensor.skip_frames(30)
sensor.set_auto_gain(False)  # must turn this off to prevent image washout...
sensor.set_auto_whitebal(False)  # must turn this off to prevent image washout...
sensor.__write_reg(0x0C, sensor.__read_reg(0x0C) | (1 << 7))

uart = UART(3, 9600)

clock = time.clock()

# 注意！与find_qrcodes不同，find_apriltags 不需要软件矫正畸变就可以工作。

# 注意，输出的姿态的单位是弧度，可以转换成角度，但是位置的单位是和你的大小有关，需要等比例换算

# f_x 是x的像素为单位的焦距。对于标准的OpenMV，应该等于2.8/3.984*656，这个值是用毫米为单位的焦距除以x方向的感光元件的长度，乘以x方向的感光元件的像素（OV7725）
# f_y 是y的像素为单位的焦距。对于标准的OpenMV，应该等于2.8/2.952*488，这个值是用毫米为单位的焦距除以y方向的感光元件的长度，乘以y方向的感光元件的像素（OV7725）

# c_x 是图像的x中心位置
# c_y 是图像的y中心位置

f_x = (2.8 / 3.984) * 160 # 默认值
f_y = (2.8 / 2.952) * 120 # 默认值
c_x = 160 * 0.5 # 默认值(image.w * 0.5)
c_y = 120 * 0.5 # 默认值(image.h * 0.5)

def degrees(radians):
    return (180 * radians) / math.pi

LED(1).on();
LED(2).on();
LED(3).on();

while(True):
    clock.tick()
    img = sensor.snapshot()
    for tag in img.find_apriltags(fx=f_x, fy=f_y, cx=c_x, cy=c_y): # 默认为TAG36H11
        img.draw_rectangle(tag.rect(), color = (255, 0, 0))
        img.draw_cross(tag.cx(), tag.cy(), color = (0, 255, 0))
        #print_args = (tag.x_translation(), tag.y_translation(), tag.z_translation(), \
        #    degrees(tag.x_rotation()), degrees(tag.y_rotation()), degrees(tag.z_rotation()))
        output_str="[%d,%d,%d]" % (160-tag.cx(),120-tag.cy(),abs(tag.z_translation())) #方式1
        print('you send:',output_str)
        uart.write(output_str+'\n')
        pyb.delay(20)
        #print("Tx: %f, Ty %f, Tz %f, Rx %f, Ry %f, Rz %f" % print_args)
    #print(clock.fps())

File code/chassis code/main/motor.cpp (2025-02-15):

#include "include.h"
#include <PID_v1.h>

bool rev1, rev2, rev3, rev4;
double M1PWMOUT, M2PWMOUT, M3PWMOUT, M4PWMOUT;//motor output
double in1, in2, in3, in4, M1S, M2S, M3S, M4S;//motor input
double Kp = 7, Ki = 2, Kd = 0; //PID
PID M1PID(&M1S, &M1PWMOUT, &ref1, Kp, Ki, Kd, DIRECT); //PID
PID M2PID(&M2S, &M2PWMOUT, &ref2, Kp, Ki, Kd, DIRECT);
PID M3PID(&M3S, &M3PWMOUT, &ref3, Kp, Ki, Kd, DIRECT);
PID M4PID(&M4S, &M4PWMOUT, &ref4, Kp, Ki, Kd, DIRECT);
struct motor
{
  int in1;
  int in2;
  int pwm;
  int A_out;
  int B_out;
};
motor M1, M2, M3, M4;
void macount()
{
  rev1 = digitalRead(M1.B_out);
  in1++;
}
void mbcount()
{
  rev2 = digitalRead(M2.B_out);
  in2++;
}
void mccount()
{
  rev3 = !digitalRead(M3.B_out);
  in3++;
}
void mdcount()
{
  rev4 = !digitalRead(M4.B_out);
  in4++;
}
void moving()
{
  if (M1PWMOUT > 0)
  {
    analogWrite(M1.pwm, M1PWMOUT);
    digitalWrite(M1.in1, 1);
    digitalWrite(M1.in2, 0);
  }
  else
  {
    analogWrite(M1.pwm, abs(M1PWMOUT));
    digitalWrite(M1.in1, 0);
    digitalWrite(M1.in2, 1);
  }
  if (M2PWMOUT > 0)
  {
    analogWrite(M2.pwm, M2PWMOUT);
    digitalWrite(M2.in1, 1);
    digitalWrite(M2.in2, 0);
  }
  else
  {
    analogWrite(M2.pwm, abs(M2PWMOUT));
    digitalWrite(M2.in1, 0);
    digitalWrite(M2.in2, 1);
  }
  if (M3PWMOUT > 0)
  {
    analogWrite(M3.pwm, M3PWMOUT);
    digitalWrite(M3.in1, 1);
    digitalWrite(M3.in2, 0);
  }
  else
  {
    analogWrite(M3.pwm, abs(M3PWMOUT));
    digitalWrite(M3.in1, 0);
    digitalWrite(M3.in2, 1);
  }
  if (M4PWMOUT > 0)
  {
    analogWrite(M4.pwm, M4PWMOUT);
    digitalWrite(M4.in1, 1);
    digitalWrite(M4.in2, 0);
  }
  else
  {
    analogWrite(M4.pwm, abs(M4PWMOUT));
    digitalWrite(M4.in1, 0);
    digitalWrite(M4.in2, 1);
  }
  //Serial.println("moved");
}
void stop_all()
{
  digitalWrite(M1.in1, 1);
  digitalWrite(M2.in1, 1);
  digitalWrite(M3.in1, 1);
  digitalWrite(M4.in1, 1);
  digitalWrite(M1.in2, 1);
  digitalWrite(M2.in2, 1);
  digitalWrite(M3.in2, 1);
  digitalWrite(M4.in2, 1);
  M1PWMOUT = 0;
  M2PWMOUT = 0;
  M3PWMOUT = 0;
  M4PWMOUT = 0;
  ref1 = 0;
  ref2 = 0;
  ref3 = 0;
  ref4 = 0;
}
void fail_safe()
{
  stop_all();
}
void GetM1Speed()
{
  if (rev1)
    M1S = in1;
  else
    M1S = -in1;
  in1 = 0;
}
void GetM2Speed()
{
  if (rev2)
    M2S = in2;
  else
    M2S = -in2;
  in2 = 0;
}
void GetM3Speed()
{
  if (rev3)
    M3S = in3;
  else
    M3S = -in3;
  in3 = 0;
}
void GetM4Speed()
{
  if (rev4)
    M4S = in4;
  else
    M4S = -in4;
  in4 = 0;
}
void Speed()
{
  GetM1Speed();
  GetM2Speed();
  GetM3Speed();
  GetM4Speed();
}
void setspeed()
{
  M1PID.Compute();
  M2PID.Compute();
  M3PID.Compute();
  M4PID.Compute();
}
void PrintSpeed()
{
  Serial.println(M1S);
  Serial.println(M2S);
  Serial.println(M3S);
  Serial.println(M4S);
  Serial.println("==========");
}
void graph()
{
  Serial.print("reference:");
  Serial.print(ref1);
  Serial.print(",");
  Serial.print("speed:");
  Serial.println(M1S);
}
void InitMotor()
{
  M1.A_out = 18;
  M2.A_out = 19;
  M3.A_out = 20;
  M4.A_out = 21;
  M1.B_out = 39;
  M2.B_out = 36;
  M3.B_out = 34;
  M4.B_out = 32;
  M1.in1 = 40;
  M1.in2 = 42;
  M2.in1 = 44;
  M2.in2 = 46;
  M3.in1 = 48;
  M3.in2 = 50;
  M4.in1 = 51;
  M4.in2 = 52;
  M1.pwm = 2;
  M2.pwm = 3;
  M3.pwm = 4;
  M4.pwm = 5;
  pinMode(M1.pwm, OUTPUT);
  pinMode(M2.pwm, OUTPUT);
  pinMode(M3.pwm, OUTPUT);
  pinMode(M4.pwm, OUTPUT);
  pinMode(M1.in1, OUTPUT);
  pinMode(M1.in2, OUTPUT);
  pinMode(M2.in1, OUTPUT);
  pinMode(M2.in2, OUTPUT);
  pinMode(M3.in1, OUTPUT);
  pinMode(M3.in2, OUTPUT);
  pinMode(M4.in1, OUTPUT);
  pinMode(M4.in2, OUTPUT);
  pinMode(M1.B_out, INPUT);
  pinMode(M2.B_out, INPUT);
  pinMode(M3.B_out, INPUT);
  pinMode(M4.B_out, INPUT);
  pinMode(M1.A_out, INPUT);
  pinMode(M2.A_out, INPUT);
  pinMode(M3.A_out, INPUT);
  pinMode(M4.A_out, INPUT);
  /************/
  attachInterrupt(digitalPinToInterrupt(M1.A_out), macount, FALLING);
  attachInterrupt(digitalPinToInterrupt(M2.A_out), mbcount, FALLING);
  attachInterrupt(digitalPinToInterrupt(M3.A_out), mccount, FALLING);
  attachInterrupt(digitalPinToInterrupt(M4.A_out), mdcount, FALLING);
  M1PID.SetMode(AUTOMATIC);
  M1PID.SetSampleTime(30);
  M2PID.SetMode(AUTOMATIC);
  M2PID.SetSampleTime(30);
  M3PID.SetMode(AUTOMATIC);
  M3PID.SetSampleTime(30);
  M4PID.SetMode(AUTOMATIC);
  M4PID.SetSampleTime(30);
  M1PID.SetOutputLimits(-255, 255);
  M2PID.SetOutputLimits(-255, 255);
  M3PID.SetOutputLimits(-255, 255);
  M4PID.SetOutputLimits(-255, 255);
}
